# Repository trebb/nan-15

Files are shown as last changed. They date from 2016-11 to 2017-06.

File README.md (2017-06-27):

NaN-15 -- a 15-key chorded computer keyboard
============================================

Finished product

Firmware
--------

The firmware is based on [TMK](https://github.com/tmk/tmk_keyboard);
see ./firmware/.

In addition to its main (chorded) input mode, a few __special layers__
are available:

- a number pad,
- a set of navigation keys,
- a mouse emulation layer,
- a macro pad. (Macro recording is done in chorded mode.)

On these layers, keycodes are registered in the usual way, i.e. once
a key is pressed.

In __chorded mode__,

1. one or more keys (the "chord") are pressed down in no particular
   order;
2. once the first key of the chord is released, the keycode mapped to
   the chord is being registered;
3. any further activity is ignored until all remaining keys are
   released.

The chorded-mode keyboard is divided into sections, and there are a
few restrictions as to the possible chords.  These restrictions and
the sectioning make it possible to fit the chordmaps into EEPROM where
they are on-the-fly editable.

The __principal section__ comprises the top three rows where a chord can
consist of up to one key from each of the four columns. This section
is switchable from its lower to an upper level, providing room for 511
different keycodes.  Each keycode is stored with its own set of the
four modfiers Right Alt, Left Alt, Left Shift, and Left Control.

The __Fn section__ occupies the same 12 keys as the principal section.
It has two levels that are bound to the function chords Fn0 and Fn1.
A chord in the Fn section can consist of one to four keys of one
particular row, providing room for 92 different keycodes, each with
its own full set of eight modifiers.  The Fn section is used for two
flavours of modifier chords, one-shot and toggled, and a few auxiliary
chords for customization, layer switching, and chordmap printing.

The three keys on the __bottom row__ form their own little section.  The
seven chords located here select the upper level of the principal
section or one of the Fn section levels, and perform a keyboard reset.

The special layers and the bottom row are immutable, but both
principal section and Fn section can be __customized__ at any time by
swapping chords.

There is storage for eight __chord macros__.  Each can record up to six
chords (including modifiers).  Recorded macros are played back through
dedicated macro chords in the principal section, or by keys of the
macro pad.

Both chordmap customizations and macro definitions __persist through
power cycles__.

Self-Documentation
------------------

The keyboard is able to __print__ its current chordmap tables by
"typing" them to the host computer.  Depending on the host computer's
keymap, the output of this operation may appear a bit mangled
([Example, affected by QWERTZ layout
setting](https://trebb.github.io/nan-15/chordmap.txt)).

See ./firmware/cheatsheet-generator/ for a tool that converts the
textual chordmap into a graphical representation (Example: [page
1](https://trebb.github.io/nan-15/default-chordmap1.svg), [page
2](https://trebb.github.io/nan-15/default-chordmap2.svg)), and for a
similar tool that extracts documentation of the [keyboard
LEDs](https://trebb.github.io/nan-15/leds.svg) from the firmware
source code.

Hardware
--------

See ./hardware/.

The main parts are three PCBs (top plate, PCB proper, and bottom
plate) and a 3D-printed frame.

It uses Cherry MX-style switches and an ATmega32U2-MU MCU.  There are
12 LEDs signalling keyboard state and errors.

Parts

The finished product draws about 18 mA.

Finished products

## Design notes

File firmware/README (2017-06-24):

Build firmware .hex and .eep files:

$ make KEYMAP=test all
  or
$ make KEYMAP=chord all

The factory-installed ATMEL bootloader works well in cases like the
test firmware where no EEPROM is involved.  For the chord firmware you
need to upload the LUFA bootloader (attach USBasp programmer):

$ make bootloader-dfu

Upload firmware to keyboard (press reset button):

$ make KEYMAP=test dfu
  or
$ make KEYMAP=chord dfu
$ make KEYMAP=chord dfu-ee

Generate keyboard documentation:

$ cd cheatsheet-generator
$ make

The chordmap cheatsheet is genereated from the textual represention in
./cheatsheet-generator/chordmap.txt.  To create a fresh chordmap.txt
reflecting the current customization state of the keyboard, invoke

$ cat > chordmap.txt

On the keyboard, press the appropriate chord to initiate chordmap
printing and wait for it to finish, then press Control-C to exit the
command.

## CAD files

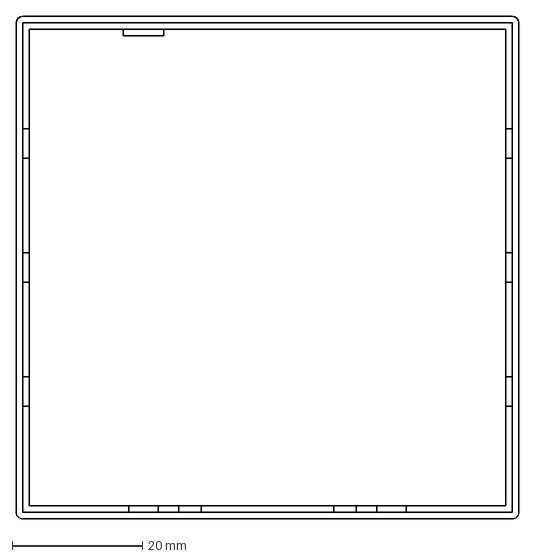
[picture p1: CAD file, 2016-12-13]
hardware/frame.dxf
77.3 x 77.3 mm

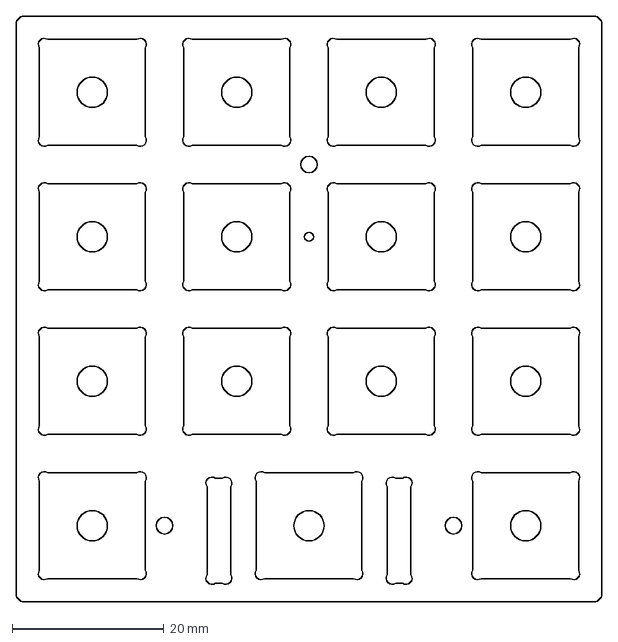
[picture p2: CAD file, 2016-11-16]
hardware/top-plate.dxf
77.2 x 77.2 mm

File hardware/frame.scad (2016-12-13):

h_key = dxf_dim(file="frame.dxf", name="key",
                layer="side-view", origin=[0, 0], scale=1);
h_top_plate = dxf_dim(file="frame.dxf", name="tpl",
                      layer="side-view", origin=[0, 0], scale=1);
h_mid = dxf_dim(file="frame.dxf", name="mid",
                layer="side-view", origin=[0, 0], scale=1);
h_bottom_plate = dxf_dim(file="frame.dxf", name="bpl",
                         layer="side-view", origin=[0, 0], scale=1);
h_label_clearance = dxf_dim(file="frame.dxf", name="lbl",
                layer="side-view", origin=[0, 0], scale=1);
x0_cable = dxf_dim(file="frame.dxf", name="x0cable",
                layer="cable", origin=[0, 0], scale=1);
y0_cable = dxf_dim(file="frame.dxf", name="y0cable",
                layer="cable", origin=[0, 0], scale=1);
delta_cx = dxf_dim(file="frame.dxf", name="delta_cx",
                   layer="cable", origin=[0, 0], scale=1);
delta_cy = dxf_dim(file="frame.dxf", name="delta_cy",
                   layer="cable", origin=[0, 0], scale=1);
nan_15_h = dxf_dim(file="frame.dxf", name="nan-15-h",
                   layer="side-view", origin=[0, 0], scale=1);
epsilon = 1;

difference() {
  union() {
    difference() {
      color("green", $fa = 5, $fs = 0.2) {
        translate([0, 0, 0]) {
          difference() {
            rotate_extrude() {
              import(file = "frame.dxf", layer = "outline-profile-2");
            }
            translate([-50, 0, -50]) {
              cube(100);
            }
            translate([0, -50, -50]) {
              cube(100);
            }
          }
          rotate_extrude() {
            import(file = "frame.dxf", layer = "profile-2-handle");
          }
          rotate([90, 0, 90]) {
            linear_extrude(height = delta_cx, $fa = 1, $fs = 0.2) {
              import(file = "frame.dxf", layer = "outline-profile-2");
            }
          }
        }
        translate([0, delta_cy, 0]) {
          difference() {
            rotate_extrude() {
              import(file = "frame.dxf", layer = "outline-profile-2");
            }
            translate([-50, -100, -50]) {
              cube(100);
            }
            translate([0, -50, -50]) {
              cube(100);
            }
          }
          rotate_extrude() {
            import(file = "frame.dxf", layer = "profile-2-handle");
          }
          rotate([90, 0, 0]) {
            linear_extrude(height = delta_cy) {
              import(file = "frame.dxf", layer = "outline-profile-2");
            }
          }
        }
        translate([delta_cx, 0, 0]) {
          difference() {
            rotate_extrude() {
              import(file = "frame.dxf", layer = "outline-profile-2");
            }
            translate([-50, 0, -50]) {
              cube(100);
            }
            translate([-100, -50, -50]) {
              cube(100);
            }
          }
          rotate_extrude() {
            import(file = "frame.dxf", layer = "profile-2-handle");
          }
          rotate([90, 0, 180]) {
            linear_extrude(height = delta_cy) {
              import(file = "frame.dxf", layer = "outline-profile-2");
            }
          }
        }
        translate([delta_cx, delta_cy, 0]) {
          difference() {
            rotate_extrude() {
              import(file = "frame.dxf", layer = "outline-profile-2");
            }
            translate([-50, -100, -50]) {
              cube(100);
            }
            translate([-100, -50, -50]) {
              cube(100);
            }
          }
          rotate_extrude() {
            import(file = "frame.dxf", layer = "profile-2-handle");
          }
          rotate([90, 0, 270]) {
            linear_extrude(height = delta_cx) {
              import(file = "frame.dxf", layer = "outline-profile-2");
            }
          }
        }

        translate([x0_cable - 7.5, delta_cy, 0]) {
          rotate_extrude() {
            import(file = "frame.dxf", layer = "profile-2-handle");
          }
        }
        translate([x0_cable + 7.5, delta_cy, 0]) {
          rotate_extrude() {
            import(file = "frame.dxf", layer = "profile-2-handle");
          }
        }
        translate([x0_cable + 7.5, delta_cy, 0]) {
          rotate([90, 0, 270]) {
            linear_extrude(height = 15) {
              import(file = "frame.dxf", layer = "profile-2-handle");
            }
          }
        }

        for(i = [-21:7:21]) {
          translate([delta_cx, delta_cy / 2 + i , 0]) {
            rotate_extrude() {
              import(file = "frame.dxf", layer = "profile-2-handle");
            }
          }
          translate([0, delta_cy / 2 + i , 0]) {
            rotate_extrude() {
              import(file = "frame.dxf", layer = "profile-2-handle");
            }
          }
        }

      }
      translate([0, 0, -50]) {
        hull() {
          linear_extrude(height = 100) {
            import(file = "frame.dxf", layer = "plate-support");
          }
        }
      }
      translate([delta_cx - x0_cable + 6, delta_cy + 1.8, nan_15_h]) {
        rotate([90, 0, 180]) {
          linear_extrude(height = 2) {
            text("NaN-15", halign = "left", valign = "center", font = "DejaVu Sans:style=Bold", size = 4, spacing = 1.1);
          }
        }
      }
    }
    translate([0, 0, 0]) {
      linear_extrude(height = h_mid) {
        import(file = "frame.dxf", layer = "plate-support");
      }
    }
    translate([0, 0, 0]) {
      linear_extrude(height = h_mid - 1) {
        import(file = "frame.dxf", layer = "bottom-support");
      }
    }
  } /* union */
  color("cyan", $fa = 5, $fs = 0.2) {
    translate([x0_cable, y0_cable, 0]) {
      rotate([-90, 0, 0]) {
        rotate_extrude() {
          import(file = "frame.dxf", layer = "cable-shape");
        }
      }
    }
  }
  translate([x0_cable, y0_cable + 15, 0]) {
    rotate([90, 0, 0]) {
      linear_extrude(height = 30) {
        import(file = "frame.dxf", layer = "cable-chamfer");
      }
    }
  }
}

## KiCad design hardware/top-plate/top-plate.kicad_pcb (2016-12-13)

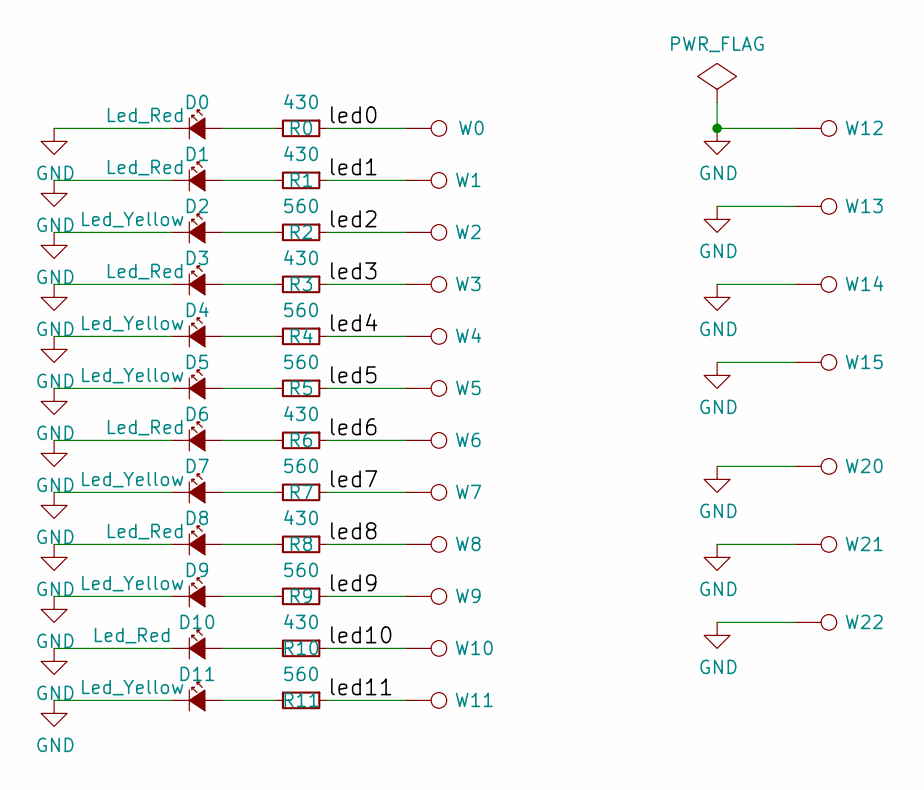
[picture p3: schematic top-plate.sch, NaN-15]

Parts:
D0, D1, D3, D6, D8, D10: Led_Red; LED_1206_REVERSE
D2, D4, D5, D7, D9, D11: Led_Yellow; LED_1206_REVERSE
R0, R1, R3, R6, R8, R10: 430; R_1206
R2, R4, R5, R7, R9, R11: 560; R_1206
W0, W1, W2, W3, W4, W5, W6, W7, W8, W9, W10, W11, W12, W13, W14, W15: TEST_1P; SolderWirePad_2mm_1-2mmDrill_no_legend
W20, W21, W22: TEST_1P; MountingHole_2.2mm_M2_Pad

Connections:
/led0: R0.1, W0.1
/led1: R1.1, W1.1
/led2: R2.1, W2.1
/led3: R3.1, W3.1
/led4: R4.1, W4.1
/led5: R5.1, W5.1
/led6: R6.1, W6.1
/led7: R7.1, W7.1
/led8: R8.1, W8.1
/led9: R9.1, W9.1
/led10: R10.1, W10.1
/led11: R11.1, W11.1
GND: D0.1 (K), D1.1 (K), D2.1 (K), D3.1 (K), D4.1 (K), D5.1 (K), D6.1 (K), D7.1 (K), D8.1 (K), D9.1 (K), D10.1 (K), D11.1 (K), W12.1, W13.1, W14.1, W15.1, W20.1, W21.1, W22.1
unnamed: D0.2 (A), R0.2
unnamed: D1.2 (A), R1.2
unnamed: D2.2 (A), R2.2
unnamed: D3.2 (A), R3.2
unnamed: D4.2 (A), R4.2
unnamed: D5.2 (A), R5.2
unnamed: D6.2 (A), R6.2
unnamed: D7.2 (A), R7.2
unnamed: D8.2 (A), R8.2
unnamed: D9.2 (A), R9.2
unnamed: D10.2 (A), R10.2
unnamed: D11.2 (A), R11.2

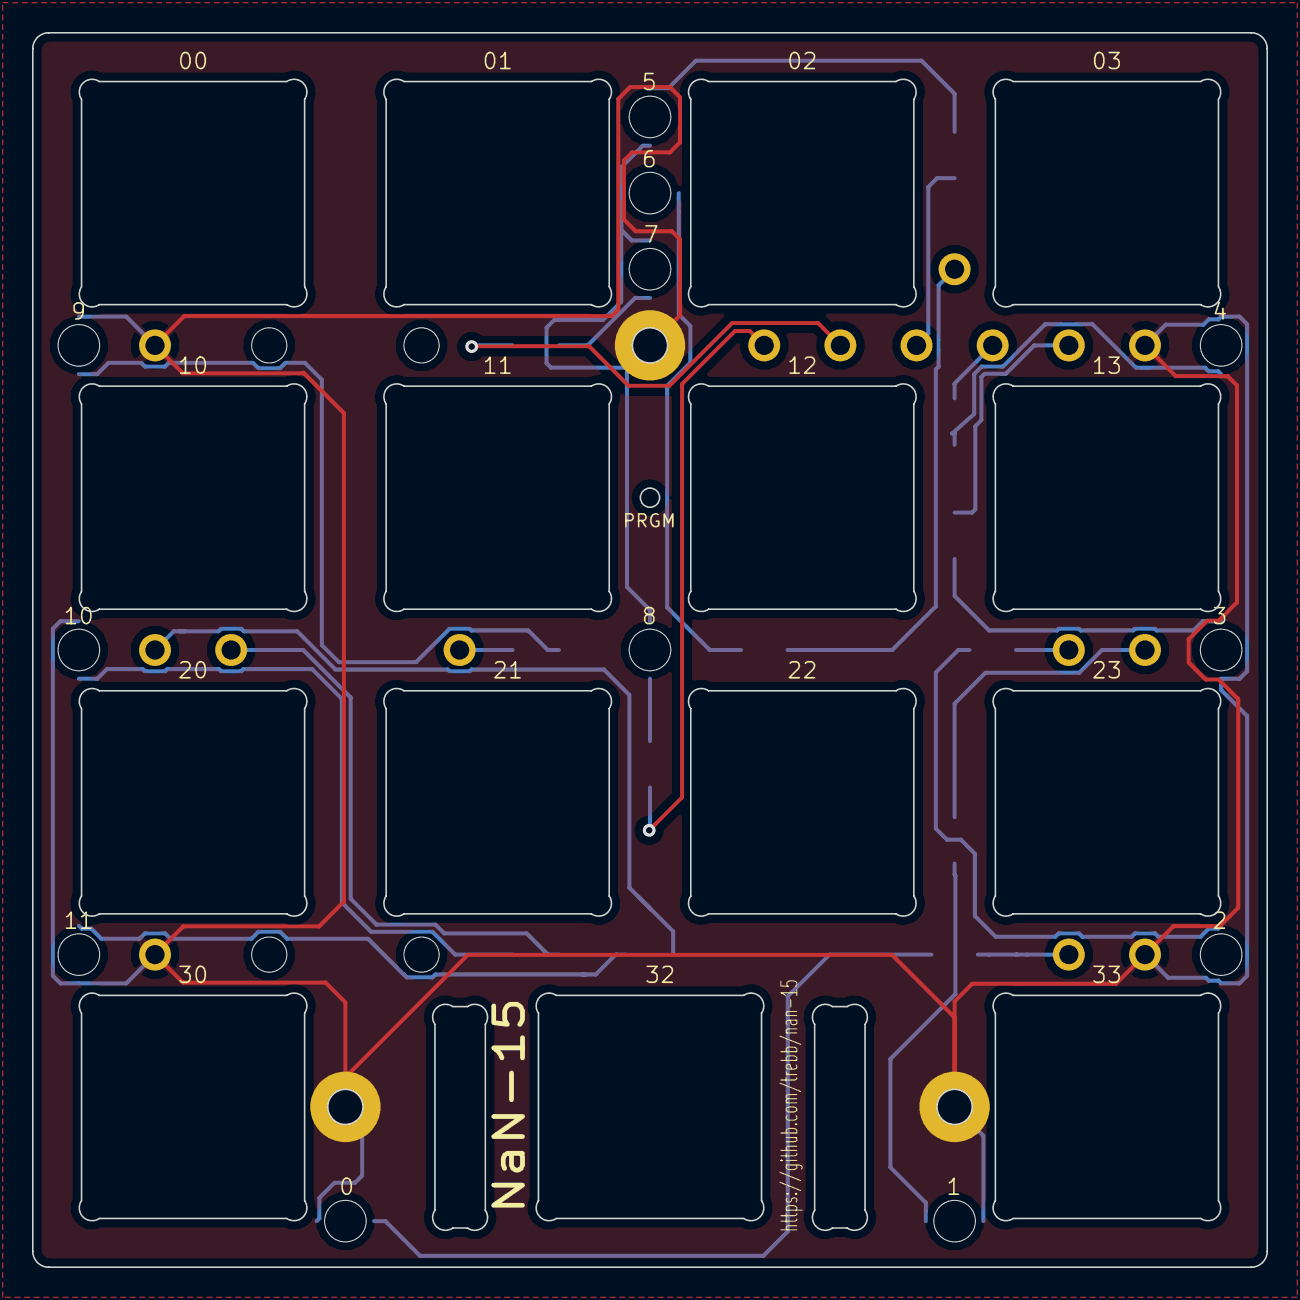
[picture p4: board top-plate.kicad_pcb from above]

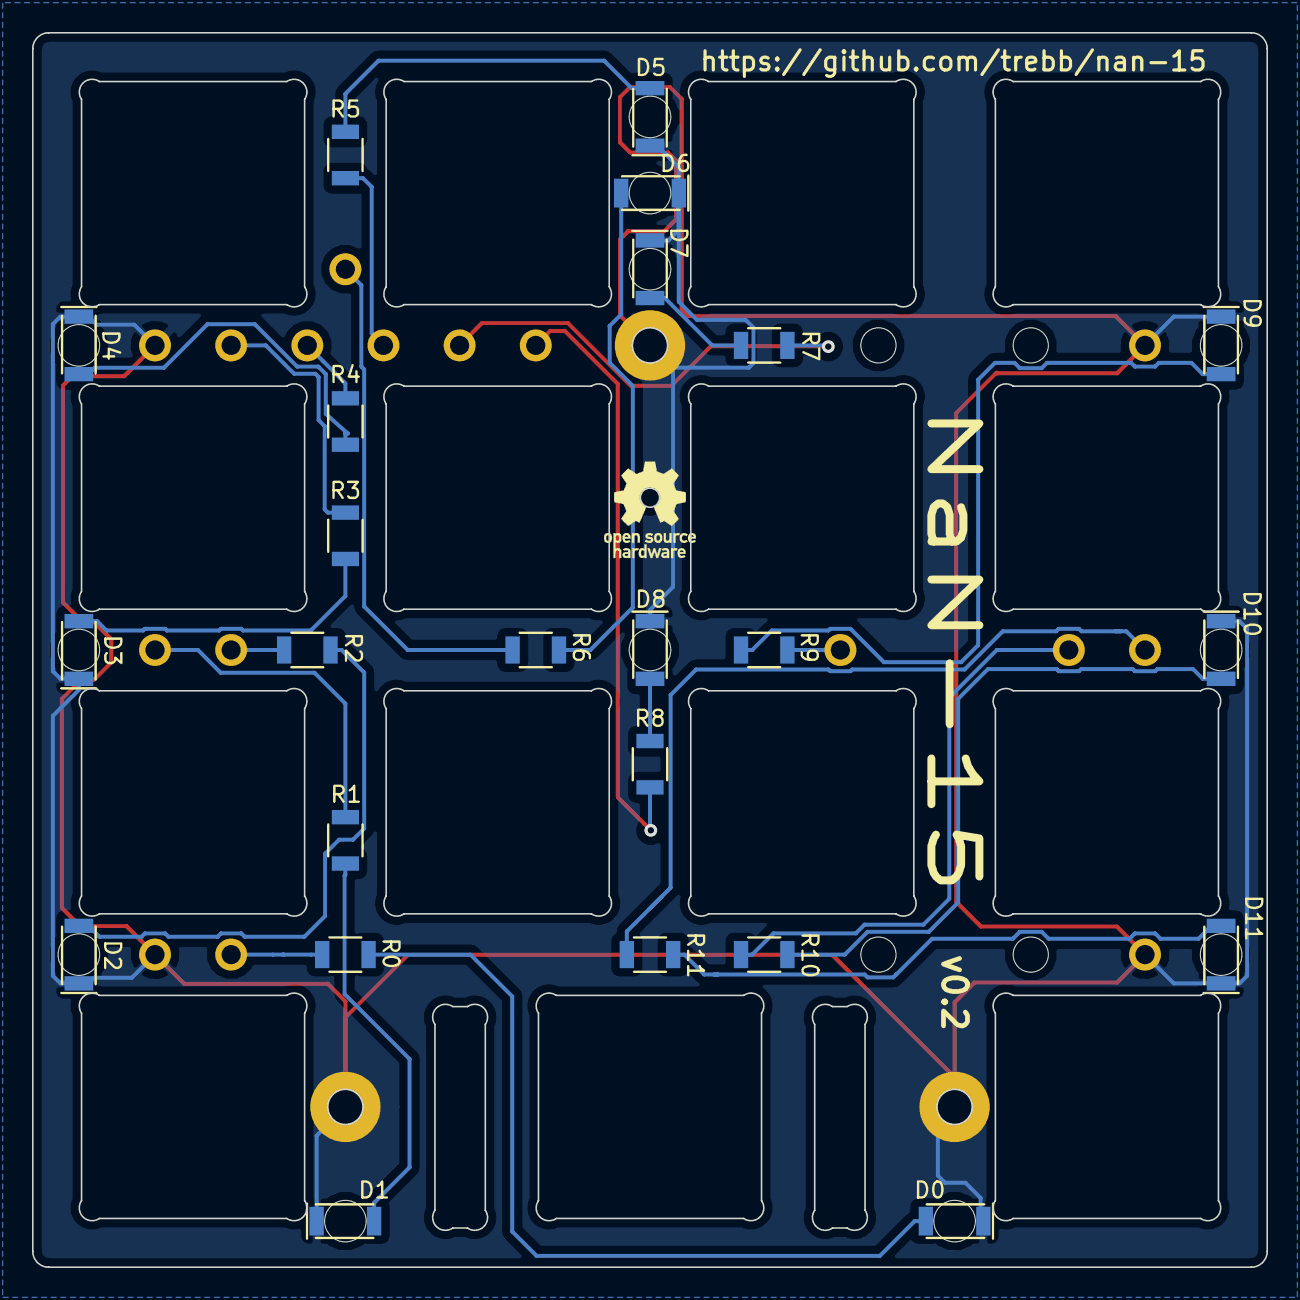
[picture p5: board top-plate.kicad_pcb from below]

Board: 2 copper layers, 77.2 x 77.2 mm, 47 parts (24 on the bottom side), 25 nets.

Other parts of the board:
HS4, HS5, HS6, HS7: HEATSINK; MountingHole_2.2mm_M2

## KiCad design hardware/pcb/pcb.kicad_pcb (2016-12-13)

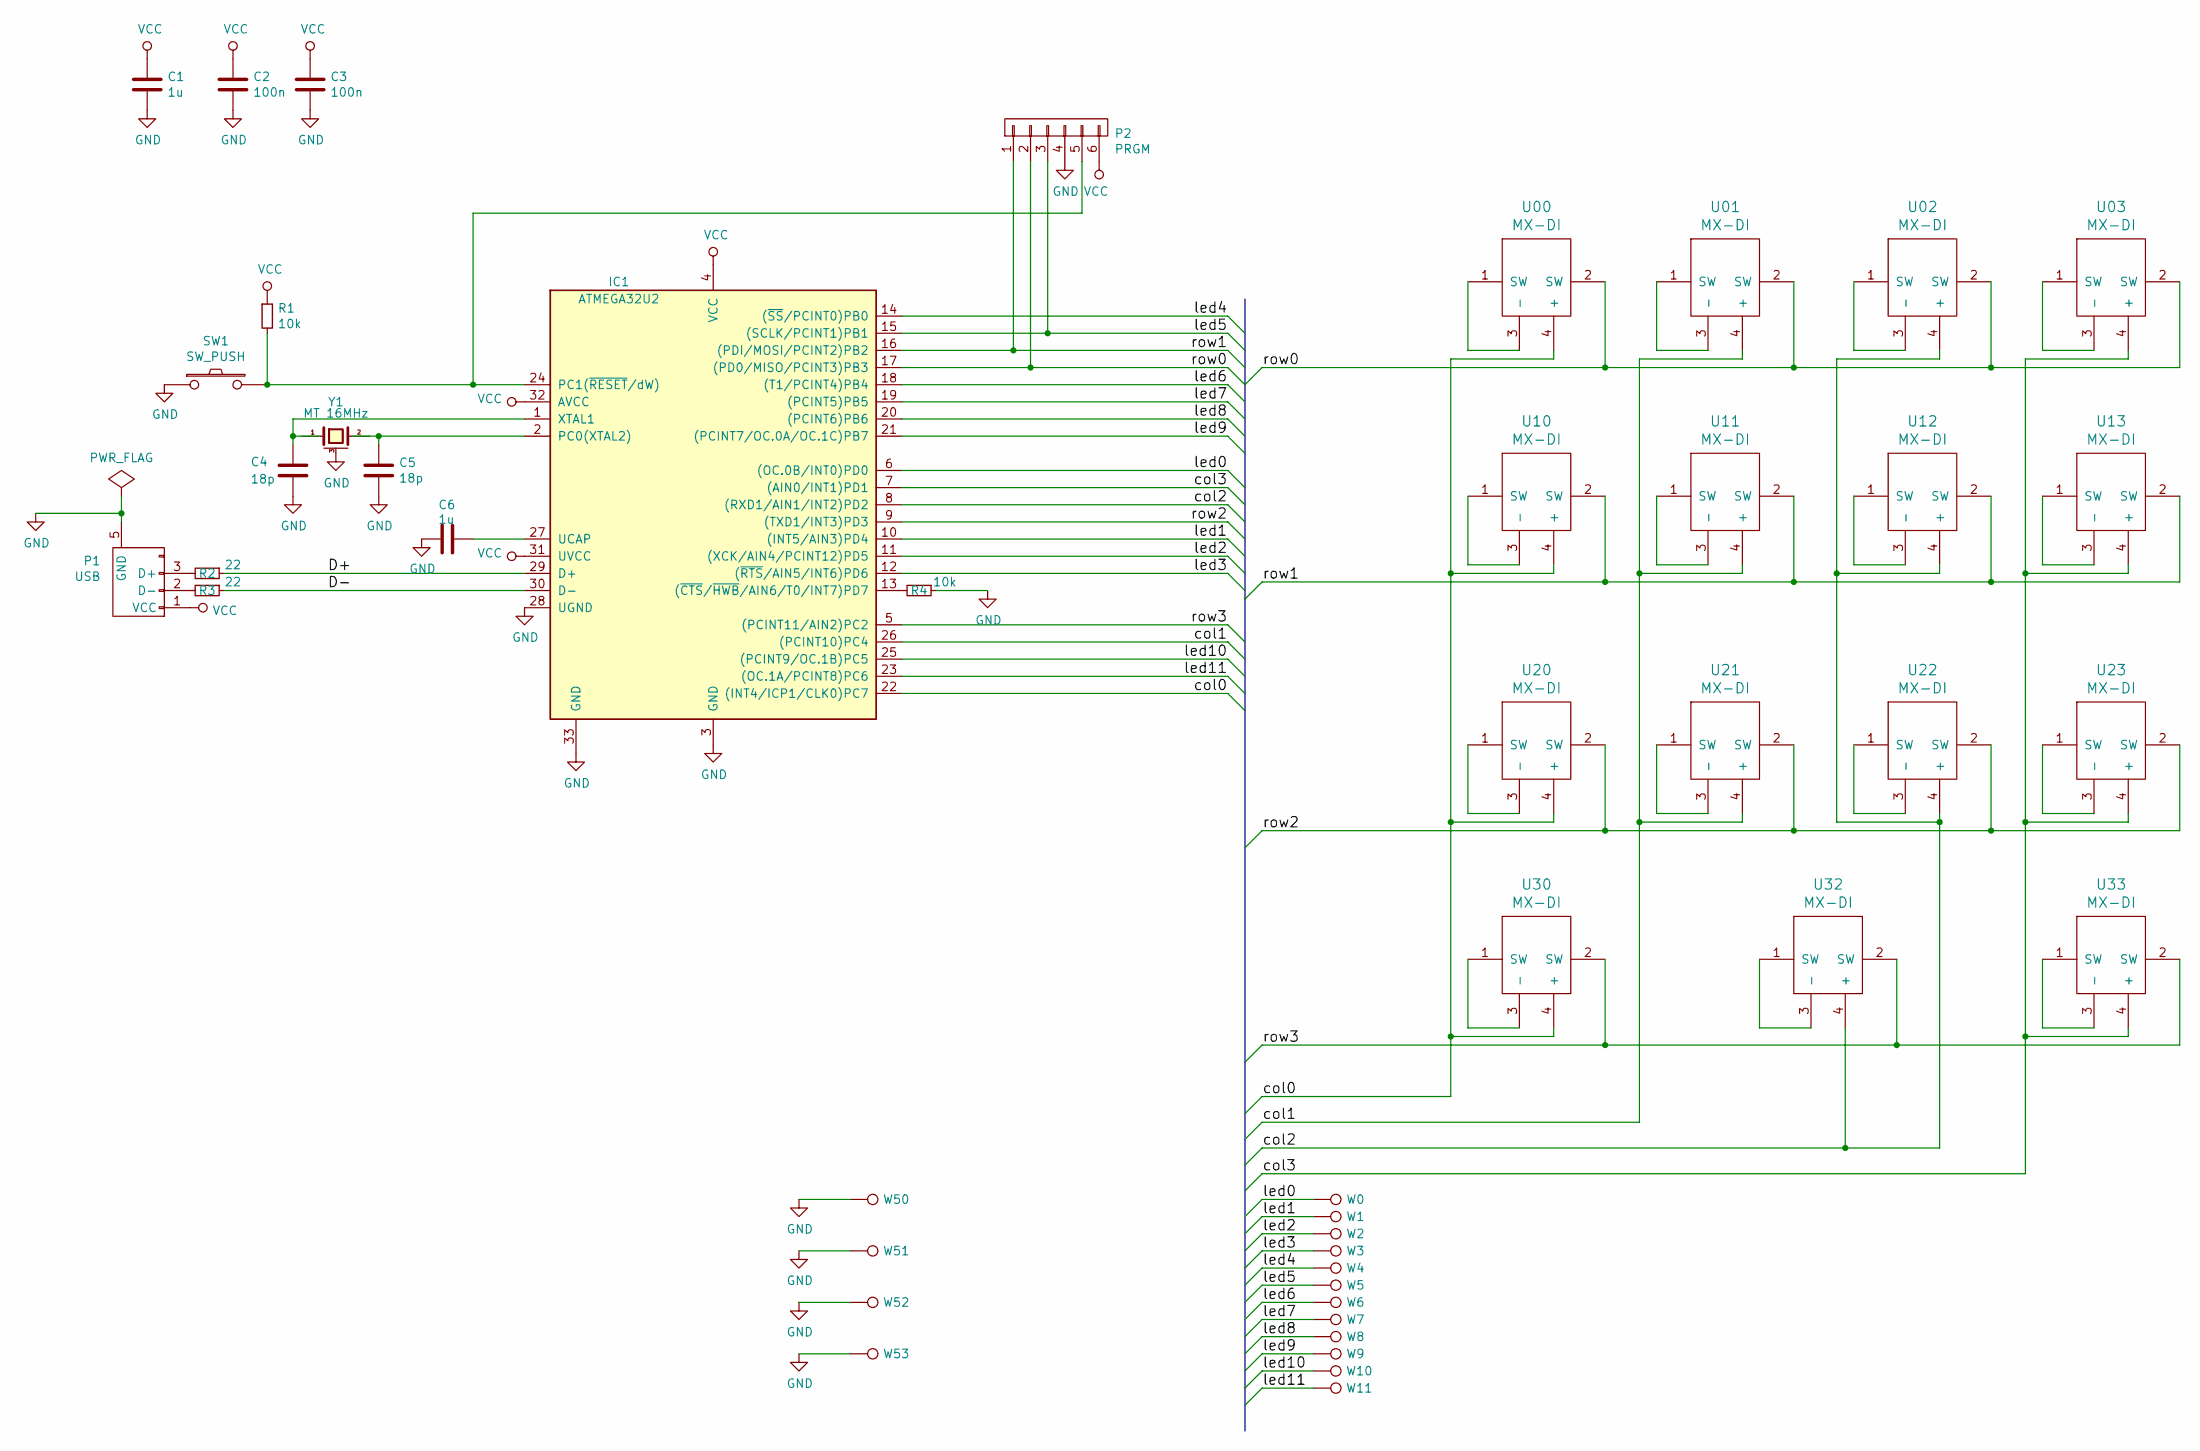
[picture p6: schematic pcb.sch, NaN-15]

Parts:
C1, C6: 1u; C_1206
C2, C3: 100n; C_1206
C4, C5: 18p; C_1206
IC1: ATMEGA32U2; QFN-32-1EP_5x5mm_Pitch0.5mm
P1: USB; SolderWirePad_4xInline_1mmDrill
P2: PRGM; Program_1x06
R1, R4: 10k; R_1206
R2, R3: 22; R_1206
SW1: SW_PUSH; button_3x6_smd
U00, U01, U02, U03, U10, U11, U12, U13, U20, U21, U22, U23, U30, U32, U33: MX-DI; MXDIODE
W0, W1, W2, W3, W4, W5, W6, W7, W8, W9, W10, W11, W50, W51, W52, W53: TEST_1P; SolderWirePad_2mm_1-2mmDrill_no_legend
Y1: MT 16MHz; crystal_MT_32x25

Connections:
/D+: IC1.29 (D+), R2.1
/D-: IC1.30 (D-), R3.1
/col0: IC1.22 ((INT4/ICP1/CLK0)PC7), U00.4 (+), U10.4 (+), U20.4 (+), U30.4 (+)
/col1: IC1.26 ((PCINT10)PC4), U01.4 (+), U11.4 (+), U21.4 (+)
/col2: IC1.8 ((RXD1/AIN1/INT2)PD2), U02.4 (+), U12.4 (+), U22.4 (+), U32.4 (+)
/col3: IC1.7 ((AIN0/INT1)PD1), U03.4 (+), U13.4 (+), U23.4 (+), U33.4 (+)
/led0: IC1.6 ((OC.0B/INT0)PD0), W0.1
/led1: IC1.10 ((INT5/AIN3)PD4), W1.1
/led2: IC1.11 ((XCK/AIN4/PCINT12)PD5), W2.1
/led3: IC1.12 ((~RTS~/AIN5/INT6)PD6), W3.1
/led4: IC1.14 ((~SS~/PCINT0)PB0), W4.1
/led5: IC1.15 ((SCLK/PCINT1)PB1), P2.3, W5.1
/led6: IC1.18 ((T1/PCINT4)PB4), W6.1
/led7: IC1.19 ((PCINT5)PB5), W7.1
/led8: IC1.20 ((PCINT6)PB6), W8.1
/led9: IC1.21 ((PCINT7/OC.0A/OC.1C)PB7), W9.1
/led10: IC1.25 ((PCINT9/OC.1B)PC5), W10.1
/led11: IC1.23 ((OC.1A/PCINT8)PC6), W11.1
/row0: IC1.17 ((PD0/MISO/PCINT3)PB3), P2.2, U00.2 (SW), U01.2 (SW), U02.2 (SW), U03.2 (SW)
/row1: IC1.16 ((PDI/MOSI/PCINT2)PB2), P2.1, U10.2 (SW), U11.2 (SW), U12.2 (SW), U13.2 (SW)
/row2: IC1.9 ((TXD1/INT3)PD3), U20.2 (SW), U21.2 (SW), U22.2 (SW), U23.2 (SW)
/row3: IC1.5 ((PCINT11/AIN2)PC2), U30.2 (SW), U32.2 (SW), U33.2 (SW)
GND: C1.2, C2.2, C3.2, C4.2, C5.2, C6.1, IC1.3 (GND), IC1.28 (UGND), IC1.33 (GND), P1.5 (GND), P2.4, R4.1, SW1.1, W50.1, W51.1, W52.1, W53.1, Y1.3 (case)
unnamed: C4.1, IC1.1 (XTAL1)
unnamed: C5.1, IC1.2 (PC0(XTAL2))
unnamed: C6.2, IC1.27 (UCAP)
unnamed: IC1.13 ((~CTS~/~HWB~/AIN6/T0/INT7)PD7), R4.2
unnamed: IC1.24 (PC1(~RESET~/dW)), P2.5, R1.2, SW1.2
unnamed: P1.2 (D-), R3.2
unnamed: P1.3 (D+), R2.2
unnamed: U00.1 (SW), U00.3 (-)
unnamed: U01.1 (SW), U01.3 (-)
unnamed: U02.1 (SW), U02.3 (-)
unnamed: U03.1 (SW), U03.3 (-)
unnamed: U10.1 (SW), U10.3 (-)
unnamed: U11.1 (SW), U11.3 (-)
unnamed: U12.1 (SW), U12.3 (-)
unnamed: U13.1 (SW), U13.3 (-)
unnamed: U20.1 (SW), U20.3 (-)
unnamed: U21.1 (SW), U21.3 (-)
unnamed: U22.1 (SW), U22.3 (-)
unnamed: U23.1 (SW), U23.3 (-)
unnamed: U30.1 (SW), U30.3 (-)
unnamed: U32.1 (SW), U32.3 (-)
unnamed: U33.1 (SW), U33.3 (-)
VCC: C1.1, C2.1, C3.1, IC1.4 (VCC), IC1.31 (UVCC), IC1.32 (AVCC), P1.1 (VCC), P2.6, R1.1

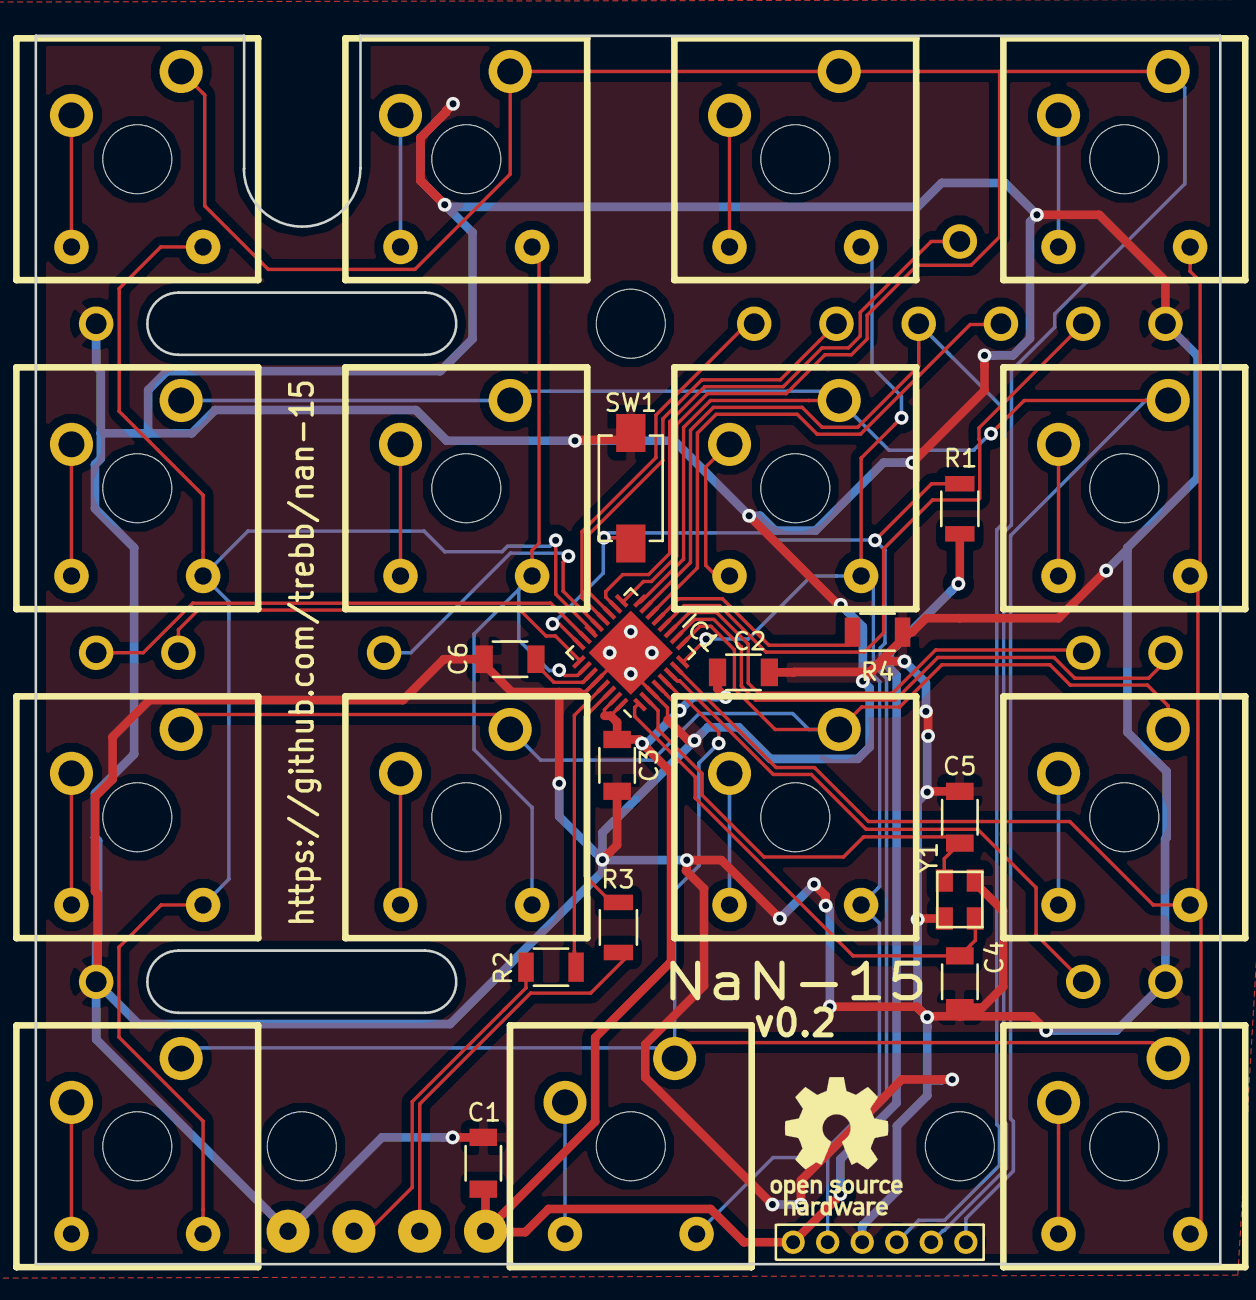
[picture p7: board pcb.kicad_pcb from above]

Board: 2 copper layers, 68.6 x 71.1 mm, 50 parts (1 on the bottom side), 46 nets.

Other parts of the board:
HS1, HS2, HS3: HEATSINK; Plain_Hole_4mm
OSHW: OSHW-Logo_28.5x30mm_SilkScreen

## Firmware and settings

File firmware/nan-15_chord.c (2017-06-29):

/*
Copyright 2013,2016 Jun Wako <wakojun@gmail.com>
Copyright 2017 Bert Burgemeister <trebbu@googlemail.com>

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
You should have received a copy of the GNU General Public License
along with this program.  If not, see <http://www.gnu.org/licenses/>.
*/

#include "actionmap.h"
#include "action_layer.h"
#include "action_util.h"
#include "debug.h"
#include "host.h"
#include "led.h"
#include "timer.h"
#include "wait.h"
#include <avr/eeprom.h>
#include <stdio.h>


/*  NaN-15 raw actionmap and LED definition
 *
 *  ,-------------------------------------------.
 *  |          |        LED5         |          |
 *  |  finger  |  finger  |  finger  |  finger  |
 *  |   1,3    |   1,2  LED6  1,1    |   1,0    |
 *  |          |          |          |          |
 *  |          |        LED7         |          |
 *  |LED9------+----------+----------+------LED4|
 *  |          |          |          |          |
 *  |  finger  |  finger  |  finger  |  finger  |
 *  |   2,3    |   2,2    |   2,1    |   2,0    |
 *  |          |          |          |          |
 *  |          |          |          |          |
 *  |LED12-----+--------LED8---------+------LED3|
 *  |          |          |          |          |
 *  |  finger  |  finger  |  finger  |  finger  |
 *  |   3,3    |   3,2    |   3,1    |   3,0    |
 *  |          |          |          |          |
 *  |          |          |          |          |
 *  |LED11-----+---------------------+------LED2|
 *  |          |                     |          |
 *  |  thumb   |        thumb        |  thumb   |
 *  |   4,2    |         4,1         |   4,0    |
 *  |          |                     |          |
 *  |        LED0                  LED1         |
 *  `-------------------------------------------'
 */



/*************************************************************
 * Define individual keys
 *************************************************************/

typedef union {
    uint8_t raw;
    struct {
        uint8_t row :3;
        uint8_t col :5;
    } key;
} keycoord_t;

enum func_id {
    /* keep those used in chrdfunc_name[] first */
    SWAP_CHRDS,
    MCR_RECORD,
    PRINT,
    RESET,
    CHG_LAYER,
    MCR_PLAY,
    FNG_CHRD,
    THB_CHRD,
    LAYER_MOMENTARY,
};

/* action_function() dispatches on AF()'s and PF()'s func_id */
#define AF(param, func_id) ACTION_FUNCTION_OPT((param), (func_id))
#define PF(row, col, func_id) AF((row) | (col)<<3, (func_id))

enum layer {
    L_DFLT = 0,
    /* keep those used in layer_name[] immdiately below L_DFLT */
    L_NUM,
    L_NAV,
    L_MSE,
    L_MCR,
    /* sublayers, only accessible from non-chord layers */
    L_NUM_FN,
};

static const action_t actionmaps[][MATRIX_ROWS][MATRIX_COLS] PROGMEM = {
    [L_DFLT] = {                /* keychord keys */
        {PF(1, 3, FNG_CHRD), PF(1, 2, FNG_CHRD), PF(1, 1, FNG_CHRD), PF(1, 0, FNG_CHRD),},
        {PF(2, 3, FNG_CHRD), PF(2, 2, FNG_CHRD), PF(2, 1, FNG_CHRD), PF(2, 0, FNG_CHRD),},
        {PF(3, 3, FNG_CHRD), PF(3, 2, FNG_CHRD), PF(3, 1, FNG_CHRD), PF(3, 0, FNG_CHRD),},
        {PF(4, 2, THB_CHRD), AC_NO,              PF(4, 1, THB_CHRD), PF(4, 0, THB_CHRD),},
    },
    [L_NUM] = {                 /* numpad */
        {AC_7,                  AC_8,  AC_9, AC_PMNS,                     },
        {AC_4,                  AC_5,  AC_6, AC_PDOT,                     },
        {AC_1,                  AC_2,  AC_3, AC_PENT,                     },
        {AF(L_DFLT, CHG_LAYER), AC_NO, AC_0, AF(L_NUM_FN, LAYER_MOMENTARY)},
    },
    [L_NAV] = {                 /* nav */
        {AC_HOME,               AC_UP,   AC_PGUP,   AC_BSPC,},
        {AC_LEFT,               AC_NO,   AC_RIGHT,  AC_INS, },
        {AC_END,                AC_DOWN, AC_PGDOWN, AC_DEL, },
        {AF(L_DFLT, CHG_LAYER), AC_NO,   AC_ESCAPE, AC_ENT, },
    },
    [L_MSE] = {                 /* mouse */
        {AC_MS_WH_LEFT,         AC_MS_UP,   AC_MS_WH_RIGHT, AC_MS_WH_UP,  },
        {AC_MS_LEFT,            AC_LSFT,    AC_MS_RIGHT,    AC_LCTL,      },
        {AC_MS_BTN3,            AC_MS_DOWN, AC_MS_BTN2,     AC_MS_WH_DOWN,},
        {AF(L_DFLT, CHG_LAYER), AC_NO,      AC_MS_BTN1,     AC_MS_BTN5,   },
    },
    [L_MCR] = {                 /* macro pad */
        {AF(KC_FN0, MCR_PLAY),  AF(KC_FN1, MCR_PLAY), AF(KC_FN2, MCR_PLAY), AF(KC_FN3, MCR_PLAY),},
        {AF(KC_FN4, MCR_PLAY),  AF(KC_FN5, MCR_PLAY), AF(KC_FN6, MCR_PLAY), AF(KC_FN7, MCR_PLAY),},
        {AF(L_NUM, CHG_LAYER),  AF(L_NAV, CHG_LAYER), AF(L_MSE, CHG_LAYER), AC_SPC,              },
        {AF(L_DFLT, CHG_LAYER), AC_NO,                AC_ESCAPE,            AC_ENT,              },
    },
    [L_NUM_FN] = {                 /* numpad sublayer */
        {AC_TRNS, AC_PSLS, AC_PAST, AC_PPLS,},
        {AC_TRNS, AC_TRNS, AC_TRNS, AC_SPC, },
        {AC_TRNS, AC_TRNS, AC_TRNS, AC_BSPC,},
        {AC_TRNS, AC_NO,   AC_P0,   AC_TRNS,},
    },
};

#define MCR_LEN 6             /* chords per macro */
#define MCR_MAX 8             /* number of macros */

action_t
action_for_key(uint8_t layer, keypos_t key)
{
    return (action_t)pgm_read_word(&actionmaps[layer][key.row][key.col]);
}



/*************************************************************
 * Define keychords
 *************************************************************/

/*
 * Two keycode/modifier sets, 12 bits each.  The keyboard's
 * upper/lower-level state (which is independent of the mods stored
 * here) determines the actual pair member to be reported.  A struct {
 * struct ... struct ... } (containing 2 12-bit structs) would be a
 * better representation but doesn't seem to pack properly.
 */
typedef struct {
    uint8_t code_lo :8;
    uint8_t mods_lo :4;
    uint8_t code_up :8;
    uint8_t mods_up :4;
} keypair_t;

/* keypair_t mods:  3210
 *   bit 0          |||+- Left Control
 *   bit 1          ||+-- Left Shift
 *   bit 2          |+--- Left Alt
 *   bit 3          +---- Right Alt (not Left GUI!)
 */
enum keypair_mod {
    No = 0x00,                /* no mod */
    Co = 0x01,                /* Left Control */
    Sh = 0x02,                /* Left Shift */
    Al = 0x04,                /* Left Alt */
    Ag = 0x08,                /* AltGr/Right Alt */
};

/* AltGr in keypair mods becomes Alt in mods */
#define KEYPAIR_MODS_TO_MODS(KEYPAIR_MODS) \
    (((KEYPAIR_MODS) & ~Ag) | ((KEYPAIR_MODS) & Ag)<<3)

#define MODS_TO_KEYPAIR_MODS(MODS) \
    (((MODS) & ~(Ag<<4))>>4 | ((MODS) & Al<<4)>>3 | ((MODS) & 0x0f))

/*
 * Keychords comprising one key per column on the upper three rows
 */
#define CHRD(COL0, COL1, COL2, COL3) ((COL0)<<6 | (COL1)<<4 | (COL2)<<2 | (COL3))
#define KEYPAIR(LOWER_MODS, LOWER_CODE, UPPER_MODS, UPPER_CODE) \
    {.mods_lo = (LOWER_MODS), .code_lo = (KC_##LOWER_CODE), \
            .mods_up = (UPPER_MODS), .code_up = (KC_##UPPER_CODE)}
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

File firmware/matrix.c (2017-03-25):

/*
Copyright 2012 Jun Wako <wakojun@gmail.com>
Copyright 2017 Bert Burgemeister <trebbu@googlemail.com>

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
You should have received a copy of the GNU General Public License
along with this program.  If not, see <http://www.gnu.org/licenses/>.
*/

/*
 * scan matrix
 */

#include "debug.h"
#include "matrix.h"
#include "lufa.h"
#include <util/delay.h>


/* matrix state (1:on, 0:off) */
static matrix_row_t matrix[MATRIX_ROWS];
static matrix_row_t matrix_debouncing[MATRIX_ROWS];

static uint8_t read_rows(void);
static void init_rows(void);
static void unselect_cols(void);
static void select_col(uint8_t row);

inline uint8_t
matrix_rows(void)
{
    return MATRIX_ROWS;
}

inline uint8_t
matrix_cols(void)
{
    return MATRIX_COLS;
}

void
matrix_init(void)
{
    uint8_t i;

    /* initialize rows and cols */
    unselect_cols();
    init_rows();
    debug_enable = true;
    /* initialize matrix state: all keys off */
    for (i=0; i < MATRIX_ROWS; i++) {
        matrix[i] = 0;
        matrix_debouncing[i] = 0;
    }
}

uint8_t
matrix_scan(void)
{
    static uint8_t debouncing = DEBOUNCE;
    uint8_t col;

    for (col = 0; col < MATRIX_COLS; col++) {
        uint8_t rows, row;

        select_col(col);
        _delay_us(30);  // without this wait read unstable value.
        rows = read_rows();
        for (row = 0; row < MATRIX_ROWS; row++) {
            bool prev_bit = matrix_debouncing[row] & ((matrix_row_t)1<<col);
            bool curr_bit = rows & (1<<row);

            if (prev_bit != curr_bit) {
                matrix_debouncing[row] ^= ((matrix_row_t)1<<col);
                if (debouncing)
                    debug("bounce!: "); debug_hex(debouncing); debug("\n");
                debouncing = DEBOUNCE;
            }
            unselect_cols();
        }
    }
    if (debouncing) {
        if (--debouncing) {
            _delay_ms(1);
        } else {
            uint8_t i;

            for (i = 0; i < MATRIX_ROWS; i++)
                matrix[i] = matrix_debouncing[i];
        }
    }
    return 1;
}

inline matrix_row_t
matrix_get_row(uint8_t row)
{
    return matrix[row];
}

/* Row pin configuration
 * row: 0  1  2  3
 * pin: B3 B2 D3 C2
 */
static void
init_rows(void)
{
    /* Input with pull-up; DDR:0 (= initial state), PORT:1 */
    PORTB |=  0b00001100;
    PORTC |=  0b00000100;
    PORTD |=  0b00001000;
}

static uint8_t
read_rows(void)
{
    return
        (PINB & (1<<3) ? 0 : (1<<0)) |
        (PINB & (1<<2) ? 0 : (1<<1)) |
        (PIND & (1<<3) ? 0 : (1<<2)) |
        (PINC & (1<<2) ? 0 : (1<<3));
}

/* Column pin configuration
 * col: 0  1  2  3
 * pin: C7 C4 D2 D1
 */
static void
unselect_cols(void)
{
    /* Hi-Z (DDR:1, PORT:0) to unselect */
    DDRC  |= 0b10010000;
    PORTC |= 0b10010000;
    DDRD  |= 0b00000110;
    PORTD |= 0b00000110;
}

static void
select_col(uint8_t col)
{
    /* Output low (DDR:1, PORT:0) to select */
    switch (col) {
    case 0: PORTC &= ~(1<<7); break;
    case 1: PORTC &= ~(1<<4); break;
    case 2: PORTD &= ~(1<<2); break;
    case 3: PORTD &= ~(1<<1); break;
    }
}

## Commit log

2016-11-14 Add PCB
    [pcb.kicad_pcb, pcb.sch]
2016-11-14 Add DXF file of top plate
    [top-plate.dxf]
2016-11-16 Make pads of the QFN32 PDB footprint longer
2016-11-16 Various PCB edits
    [pcb.kicad_pcb, pcb.sch]
2016-11-16 Design a top plate
    [top-plate.dxf, top-plate.kicad_pcb, top-plate.sch]
2016-11-16 Design a bottom plate
    [bottom-plate.kicad_pcb, bottom-plate.sch, top-plate.kicad_pcb]
2016-11-18 Connect all PWM pins to LEDs; show PCB version number
    [bottom-plate.kicad_pcb, pcb.kicad_pcb, pcb.sch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]
2016-11-19 Add 3D-printable frame
    [frame.dxf, frame.scad]
2016-11-19 Print switch numbers onto top plate
    [top-plate.kicad_pcb]
2016-11-19 Minor PCB edits regarding Gerber output
    [bottom-plate.kicad_pcb, pcb.kicad_pcb, top-plate.kicad_pcb]
2016-12-07 Update version numbers on PCB silkscreens
    [bottom-plate.kicad_pcb, bottom-plate.sch, pcb.kicad_pcb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]
2016-12-13 Reduce depth of LED cutouts in frame
    [frame.dxf, frame.scad]
2017-03-05 Add support for LEDs and modifiers
2017-03-17 Improve chorded firmware
    - Editable chordmaps, stored in EEPROM
    - One-shot and toggled modifiers
    - Chordmap printing
    - Additional non-chorded layers
2017-03-26 Tweak printing output and chordmap
2017-03-28 Rearrange LED code to facilitate documentation
2017-05-28 Add LED cheatsheet generator
2017-05-28 Add forgotten KiCad files
2017-05-28 Fix bug in chordmap printing
    In second or later output attempt, the first line got mangled.
    [nan-15_chord.c]
2017-06-09 CC14 is our official USB PID (issued by pid.codes)
2017-06-24 Setting fuses isn't required; update README
2017-06-24 README: mention power consumption
2017-06-24 Swap left/right arrows in default chordmap
    [nan-15_chord.c]
2017-06-29 Bugfix: Ctrl had the wrong LEDs flash
    [nan-15_chord.c]

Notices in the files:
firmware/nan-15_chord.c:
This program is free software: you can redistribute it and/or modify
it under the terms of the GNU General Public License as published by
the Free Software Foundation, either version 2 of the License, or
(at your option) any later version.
